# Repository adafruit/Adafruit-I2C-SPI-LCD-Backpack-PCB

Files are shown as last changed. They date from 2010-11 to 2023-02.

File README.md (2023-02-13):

# i2c / SPI character LCD backpack

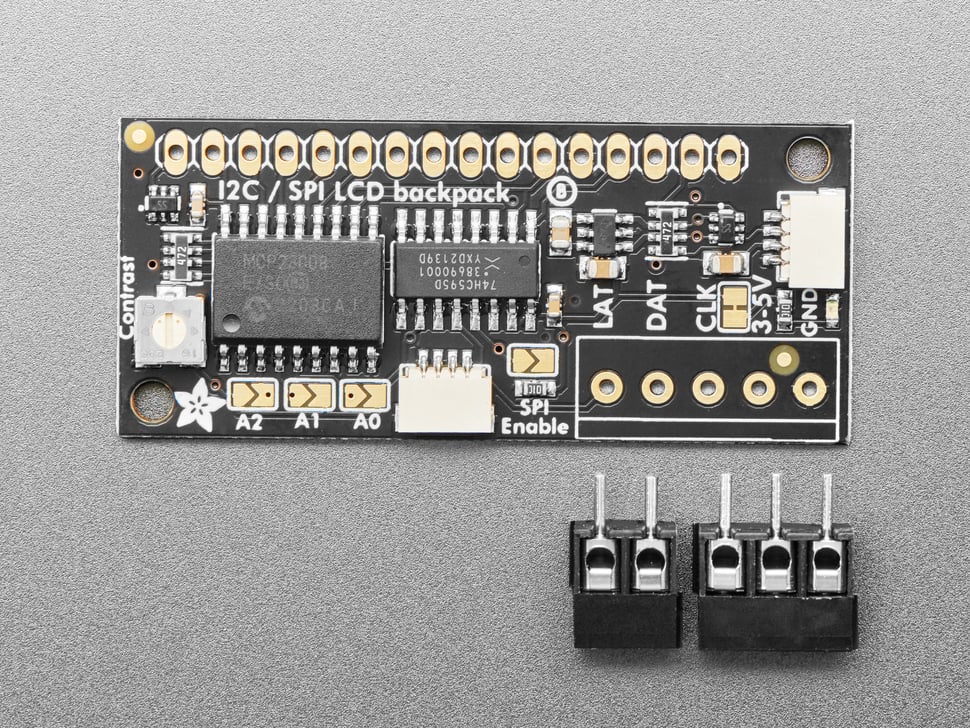
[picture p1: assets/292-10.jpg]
<a href="http://www.adafruit.com/products/292"><br/>
Click here to purchase one from the Adafruit shop
</a>

LCD backpacks reduce the number of pins needed to connect to an LCD. LCDs are a fun and easy way to have your microcontroller project talk back to you. Character LCDs are common, and easy to get, available in tons of colors and sizes. [We've written tutorials on using character LCDs with an Arduino](http://learn.adafruit.com/character-lcds) (or similar microcontroller) but find that the number of pins necessary to control the LCD can be restrictive, especially with ambitious projects. We wanted to make a 'backpack' (add-on circuit) that would reduce the number of pins without a lot of expense.

By using simple i2c and SPI input/output expanders we have reduced the number of pins (only 2 pins are needed for i2c) while still making it easy to interface with the LCD. For Arduino users, we provide a easy-to-use library that is backwards compatible with projects using the '6 pin' wiring. The breakout comes with a 2-pin and 3-pin terminal block as shown (you can snap it together to make a 5-pin terminal and then solder it to the backpack for easy wiring)

This backpack will work with any 'standard' character LCD, from 8x1 to 20x4 sizes! As long as they have a 16-pin single-line connection header at the top. [We carry a few LCDs that work great](http://www.adafruit.com/category/63_96). We suggest using our blue & white 20x4 or 16x2 LCDs. It does not work with the 16x2 OLED displays. You can try to connect our RGB 16x2 or 20x4 LCDs up but this backpack will not control the RGB backlight so you'll have to use the backpack only for the 14 digital IO pins (pins #1-14) and connect the backlight pins (#15-#18) directly to your microcontroller with 4 extra wires for color/PWM control as if they were just an RGB LED.

<b>NEW! As of February 8, 2023 - This backpack now comes with a big re-spin that makes lots of improvements:</b>

* We've added a 3-5V boost circuit so you can use this backpack to control 5V LCDs even with 3V power and logic.
* The contrast potentiometer is a lot nicer and easier to twist using a small screwdriver
* Added SparkFun qwiic compatible STEMMA QT connectors for the I2C bus so you don't even need to solder the I2C and power lines. Just wire up to your favorite micro using a STEMMA QT adapter cable. QT Cable is not included, but we have a variety in the shop.
* Functionality and size/shape are the same - mechanically and code-wise it is a drop-in replacement.
* We've also updated this PCB with Adafruit Pinguin to make a lovely and legible silkscreen.

For advanced users, this project can be used for general purpose I/O expansion, the MCP23008 has 8 i/o pins (7 are connected) with optional pull-ups, the SPI 74HC595 has 7 connected outputs.

Note: The terminal blocks included with your product may be blue or black.

[For a detailed tutorial on usage, including an Arduino library, wiring diagrams, and files, please visit the product page](http://learn.adafruit.com/i2c-spi-lcd-backpack)

### License

Adafruit invests time and resources providing this open source design, please support Adafruit and open-source hardware by purchasing products from [Adafruit](https://www.adafruit.com)!

Designed by Limor Fried/Ladyada for Adafruit Industries.

Creative Commons Attribution/Share-Alike, all text above must be included in any redistribution. See license.txt for additional details.

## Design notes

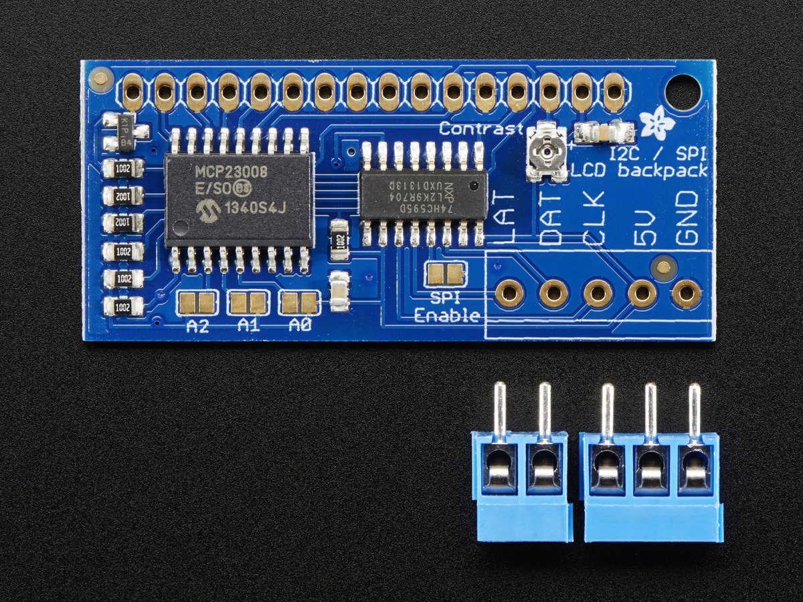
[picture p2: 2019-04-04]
assets/board.jpg

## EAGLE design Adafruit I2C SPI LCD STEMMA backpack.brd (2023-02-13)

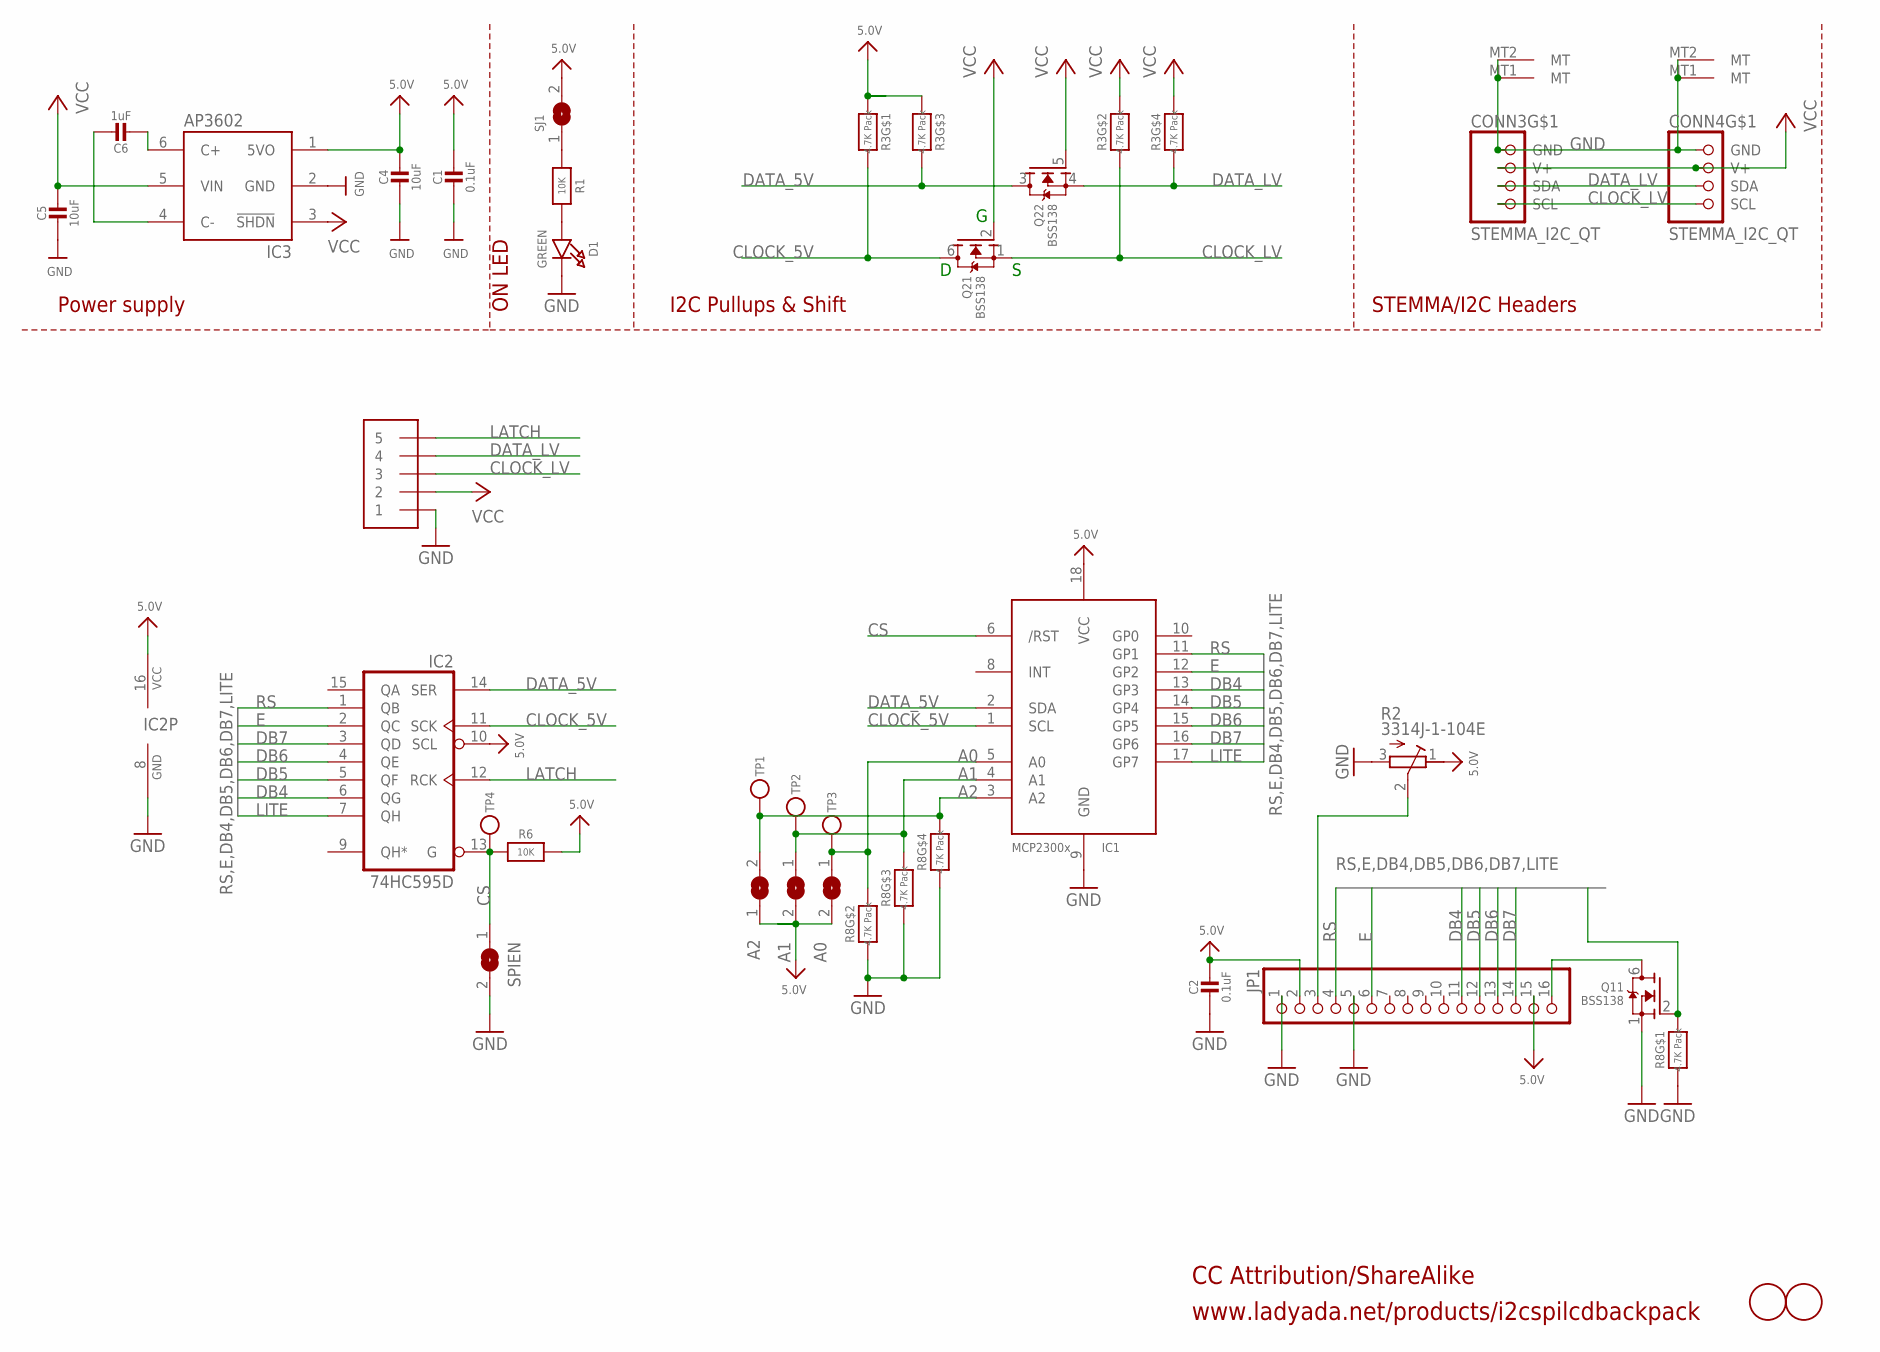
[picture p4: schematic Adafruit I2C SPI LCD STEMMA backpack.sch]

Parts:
A0, A1, A2: SOLDERJUMPER; SOLDERJUMPER_ARROW_NOPASTE
C1, C2: 0.1uF; 0603-NO
C4, C5: 10uF; 0805-NO
C6: 1uF; 0805-NO
CONN3, CONN4: STEMMA_I2C_QT; JST_SH4
D1: GREEN; CHIPLED_0603_NOOUTLINE
IC1: MCP23008/SO; SO18W
IC2: 74HC595D; SO16
IC3: AP3602/RT9361; SOT23-6
J1: 1X5; 1X05-3.5MM
JP1: PINHD-1X16; 1X16
Q1, Q2: BSS138; SOT363
R1, R6: 10K; 0603-NO
R2: 3314J-1-104E; RTRIM3314J
R3, R8: 4.7K Pack; RESPACK_4X0603
SJ1: SOLDERJUMPERCLOSED; SOLDERJUMPER_CLOSEDWIRE
SPIEN: SOLDERJUMPER; SOLDERJUMPER_ARROW_NOPASTE
TP1, TP2, TP3, TP4: TESTPOINTROUND1.5MM; TESTPOINT_ROUND_1.5MM
U$1, U$2: FIDUCIAL; FIDUCIAL_1MM

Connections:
5.0V: A0.2, A1.2, A2.1, C1.1, C2.1, C4.1, IC1.18 (VCC), IC2.10 (SCL), IC2.16 (VCC), IC3.1 (5VO), JP1.2, JP1.15, R2.1 (E), R3.1, R3.3 (1), R6.1, SJ1.2
A0: A0.1, IC1.5 (A0), R8.7 (2), TP3.P$1
A1: A1.1, IC1.4 (A1), R8.6 (2), TP2.P$1
A2: A2.2, IC1.3 (A2), R8.5 (2), TP1.P$1
CLOCK_5V: IC1.1 (SCL), IC2.11 (SCK), Q2.6 (D), R3.8 (2)
CLOCK_LV: CONN3.4 (SCL), CONN4.4 (SCL), J1.3, Q2.1 (S), R3.7 (2)
CONTRAST: JP1.3, R2.2 (S)
CS: IC1.6 (/RST), IC2.13 (G), R6.2, SPIEN.1, TP4.P$1
DATA_5V: IC1.2 (SDA), IC2.14 (SER), Q2.3 (D), R3.6 (2)
DATA_LV: CONN3.3 (SDA), CONN4.3 (SDA), J1.4, Q2.4 (S), R3.5 (2)
DB4: IC1.13 (GP3), IC2.6 (QG), JP1.11
DB5: IC1.14 (GP4), IC2.5 (QF), JP1.12
DB6: IC1.15 (GP5), IC2.4 (QE), JP1.13
DB7: IC1.16 (GP6), IC2.3 (QD), JP1.14
E: IC1.12 (GP2), IC2.2 (QC), JP1.6
GND: C1.2, C2.2, C4.2, C5.2, CONN3.1 (GND), CONN3.MT1 (MT), CONN3.MT2 (MT), CONN4.1 (GND), CONN4.MT1 (MT), CONN4.MT2 (MT), D1.C, IC1.9 (GND), IC2.8 (GND), IC3.2 (GND), J1.1, JP1.1, JP1.5, Q1.1 (S), R2.3 (A), R8.1, R8.2 (1), R8.3 (1), R8.4 (1), SPIEN.2
LATCH: IC2.12 (RCK), J1.5
LEDK: JP1.16, Q1.6 (D)
LITE: IC1.17 (GP7), IC2.7 (QH), Q1.2 (G), R8.8 (2)
unnamed: D1.A, R1.2
unnamed: R1.1, SJ1.1
unnamed: C6.2, IC3.6 (C+)
unnamed: C6.1, IC3.4 (C-)
RS: IC1.11 (GP1), IC2.1 (QB), JP1.4
VCC: C5.1, CONN3.2 (V+), CONN4.2 (V+), IC3.3 (!SHDN), IC3.5 (VIN), J1.2, Q2.2 (G), Q2.5 (G), R3.2 (1), R3.4 (1)

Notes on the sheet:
www.ladyada.net/products/i2cspilcdbackpack
CC Attribution/ShareAlike
I2C Pullups & Shift
STEMMA/I2C Headers
ON LED
Power supply

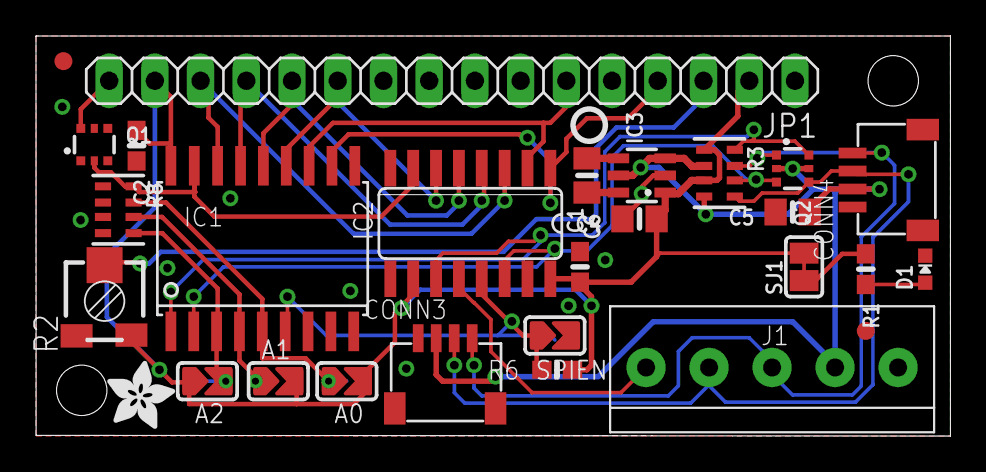
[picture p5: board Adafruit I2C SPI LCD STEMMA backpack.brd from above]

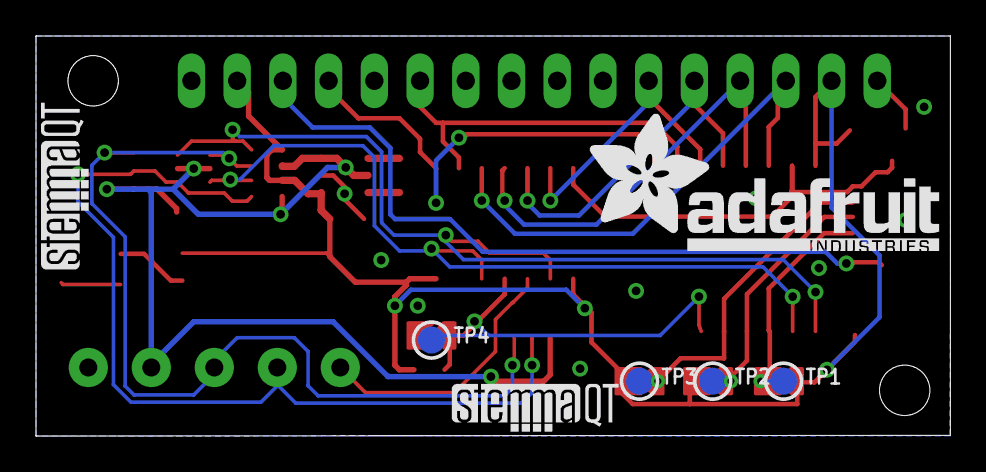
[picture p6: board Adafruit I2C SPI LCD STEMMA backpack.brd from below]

Board: 2 copper layers, 50.8 x 22.2 mm, 49 parts (8 on the bottom side), 25 nets.

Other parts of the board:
PLABEL0: PLABEL0
PLABEL1: PLABEL1
PLABEL2: PLABEL2
PLABEL3: PLABEL3
PLABEL4: PLABEL4
PLABEL5: PLABEL5
PLABEL6: PLABEL6
PLABEL7: PLABEL7
PLABEL8: PLABEL8
PLABEL9: PLABEL9
PLABEL10: PLABEL10
PLABEL11: PLABEL11
PLABEL12: PLABEL12
U$4: ADAFRUIT_3.5MM
U$7: PCBFEAT-REV-040
U$11, U$12: STEMMAQT
U$23: ADAFRUIT_TEXT_20MM

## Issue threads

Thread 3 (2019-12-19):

IOError: [Errno 121] Remote I/O error

overlordpy, 2019-12-19:
I have trying to run the LCD module with a Sm-bus backpack but every time I run the code i get this error
python i2c_lcd1602.py
Traceback (most recent call last):
`  File "i2c_lcd1602.py", line 91, in <module>
    screen = Screen(bus=1, addr=0x27, cols=16, rows=2)
  File "i2c_lcd1602.py", line 28, in __init__
    self.display_init()
  File "i2c_lcd1602.py", line 59, in display_init
    self.write4bits(0x30)
  File "i2c_lcd1602.py", line 82, in write4bits
    self.expanderWrite(value)
  File "i2c_lcd1602.py", line 87, in expanderWrite
    self.bus.write_byte_data(self.addr, 0, data|self.data_mask)
IOError: [Errno 121] Remote I/O error
`
I am using this code

`#!/usr/bin/env python

import smbus
from time import sleep

def delay(time):
    sleep(time/1000.0)

def delayMicroseconds(time):
    sleep(time/1000000.0)

class Screen():

    enable_mask = 1<<2
    rw_mask = 1<<1
    rs_mask = 1<<0
    backlight_mask = 1<<3

    data_mask = 0x00

    def __init__(self, cols = 16, rows = 2, addr=0x27, bus=1):
        self.cols = cols
        self.rows = rows
        self.bus_num = bus
        self.bus = smbus.SMBus(self.bus_num)
        self.addr = addr
        self.display_init()

    def enable_backlight(self):
        self.data_mask = self.data_mask|self.backlight_mask

    def disable_backlight(self):
        self.data_mask = self.data_mask& ~self.backlight_mask

    def display_data(self, *args):
        self.clear()
        for line, arg in enumerate(args):
            self.cursorTo(line, 0)
            self.println(arg[:self.cols].ljust(self.cols))
   
    def cursorTo(self, row, col):
        offsets = [0x00, 0x40, 0x14, 0x54]
        self.command(0x80|(offsets[row]+col))

    def clear(self):
        self.command(0x10)

    def println(self, line):
        for char in line:
            self.print_char(char)

    def print_char(self, char):
        char_code = ord(char)
        self.send(char_code, self.rs_mask)

    def display_init(self):
        delay(1.0)
        self.write4bits(0x30)
        delay(4.5)
        self.write4bits(0x30)
        delay(4.5)
        self.write4bits(0x30)
        delay(0.15)
        self.write4bits(0x20)
        self.command(0x20|0x08)
        self.command(0x04|0x08, delay=80.0)
        self.clear()
        self.command(0x04|0x02)
        delay(3)

    def command(self, value, delay = 50.0):
        self.send(value, 0)
        delayMicroseconds(delay)

    def send(self, data, mode):
        self.write4bits((data & 0xF0)|mode)
        self.write4bits((data << 4)|mode)

    def write4bits(self, value):
        value = value & ~self.enable_mask
        self.expanderWrite(value)
        self.expanderWrite(value | self.enable_mask)
        self.expanderWrite(value)

    def expanderWrite(self, data):
        self.bus.write_byte_data(self.addr, 0, data|self.data_mask)

if __name__ == "__main__":
    screen = Screen(bus=1, addr=0x27, cols=16, rows=2)
    line = " www.adeept.com "
    screen.enable_backlight()
    while True:
        screen.display_data(line, line[::-1])
        sleep(1)
        screen.display_data(line[::-1], line)
        sleep(1)
`

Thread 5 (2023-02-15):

Schematic is old

djfarrell, 2023-02-15:
This schematic is the old board, then new has two  Stemma? connectors.  The bottom connector works for I2C, the right connector does not.

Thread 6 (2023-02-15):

On the next spin...

djfarrell, 2023-02-15:
Is it possible to not block one of the LCD mounting holes? I have to notch this corner.
The top edge extends past the LCD edge by about 0.03", mounting is a little more challenging in tight spaces. I have to belt sand the board.

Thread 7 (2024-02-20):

Rust Driver for LCD Backpack

michaelkamprath, 2024-02-20:
In case anybody is interested, I made a Rust driver for the I2C interface to the Adafruit LCD Backpack. [You may find it here](https://github.com/michaelkamprath/adafruit-lcd-backpack-rust).  It is based on the standard `embedded-hal` hardware abstraction layer used on many platforms.

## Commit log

2011-12-19 clarified MCP23008 connections
    [i2cspilcdbackpack.sch]
2023-02-13 adding STEMMA version
    [Adafruit I2C SPI LCD STEMMA backpack.brd, Adafruit I2C SPI LCD STEMMA backpack.sch]

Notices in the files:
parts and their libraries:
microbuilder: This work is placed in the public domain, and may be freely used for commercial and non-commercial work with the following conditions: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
